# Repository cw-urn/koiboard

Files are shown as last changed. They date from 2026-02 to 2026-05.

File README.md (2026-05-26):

# koiboard
> What is this?
- Koiboard is a 40% ortholinear mechanical low-profile keyboard.
> How do you use it?
- Well you know how to you a keyboard, right? This one just has its keys aligned differently!
> Why did I make this?
- Honestly, I saw the simplicity of the [XYZ Work Board](https://worklouder.cc/xyz-work-board-2), plus other boards, and thought I could make it myself.

<hr>

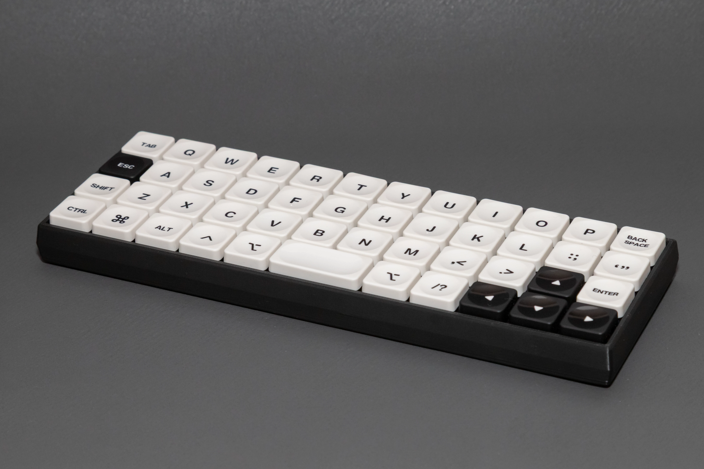
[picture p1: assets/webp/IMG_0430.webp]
Final build


<hr>

## 3D render
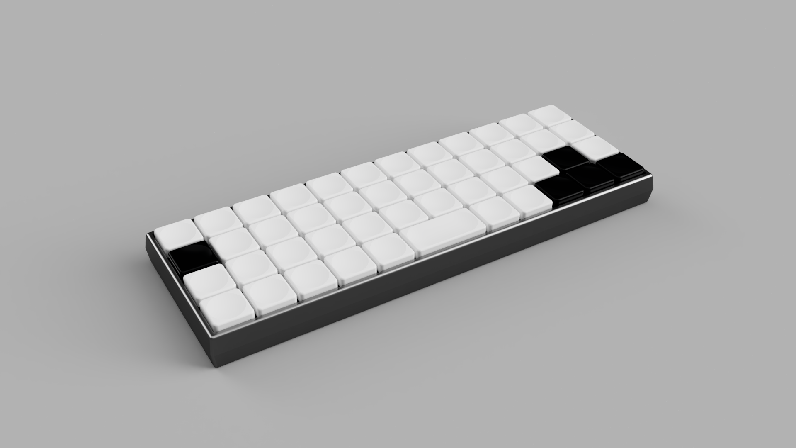
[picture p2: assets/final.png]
3D render


## PCB
[Open online PCB viewer](https://kicanvas.org/?repo=https%3A%2F%2Fgithub.com%2Fcw-urn%2Fkoiboard%2Ftree%2Fmain%2Fpcb)

### Layer 1
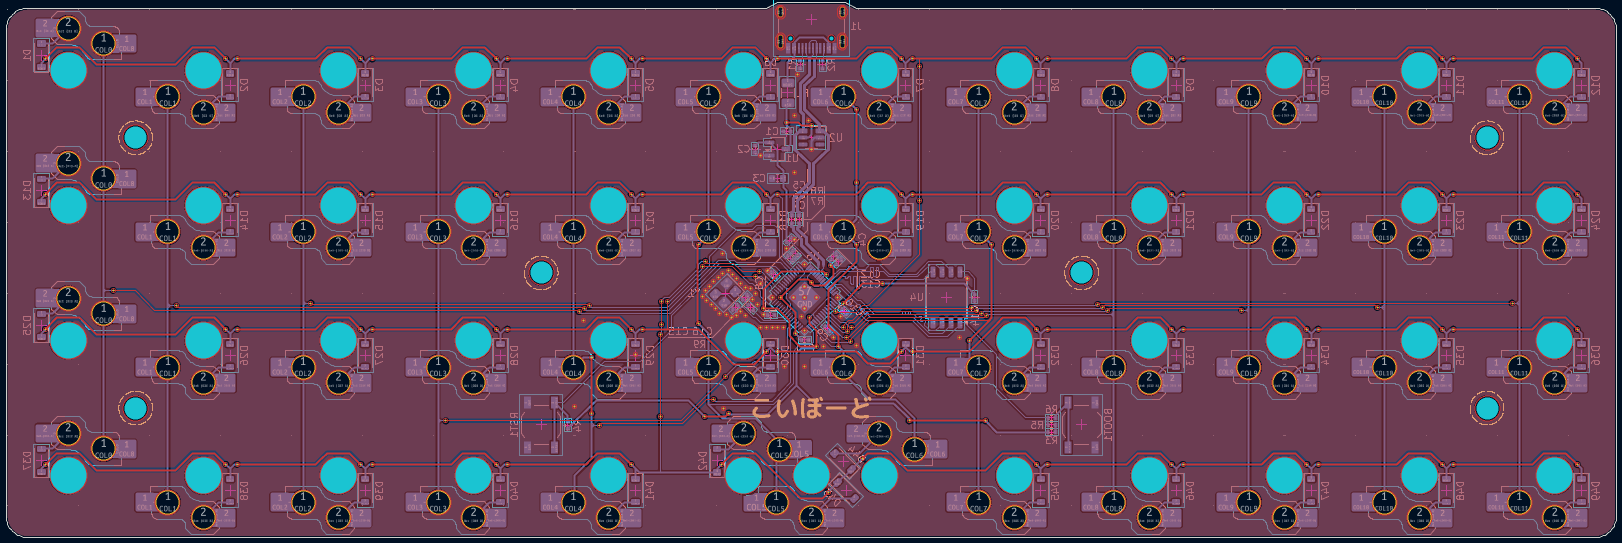
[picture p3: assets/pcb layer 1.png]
Layer 1


### Layer 2
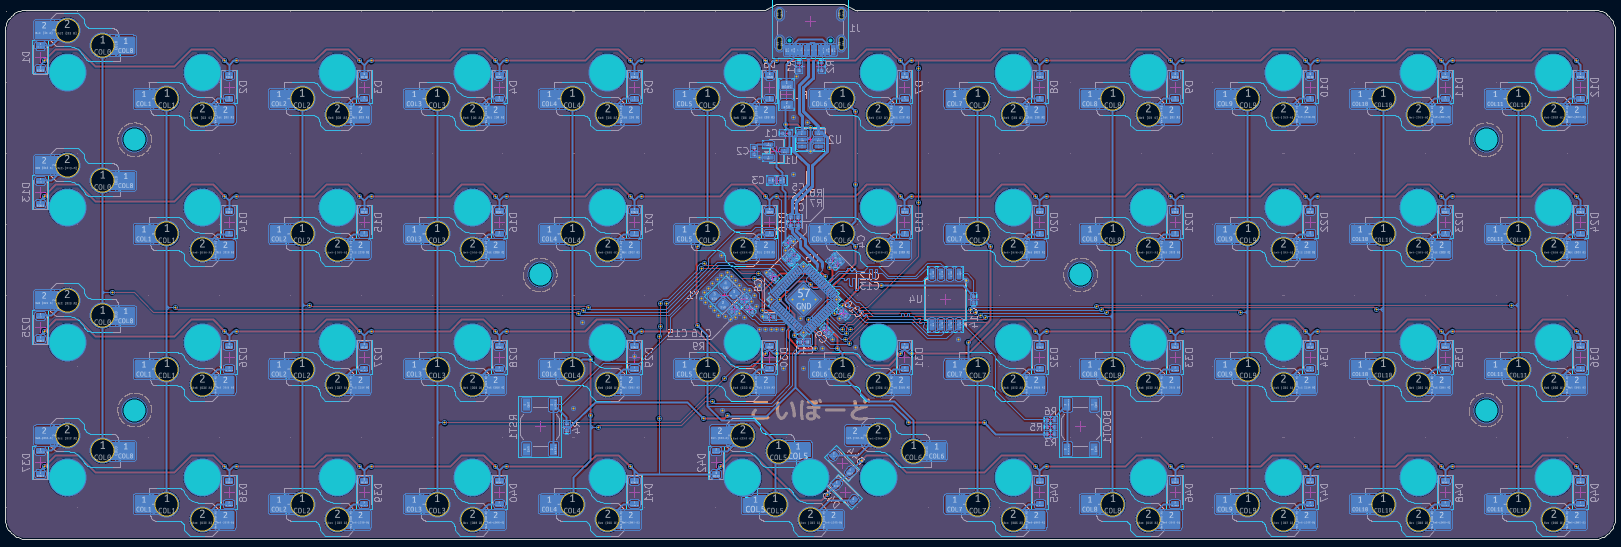
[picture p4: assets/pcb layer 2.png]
Layer 2


### PCB 3D render
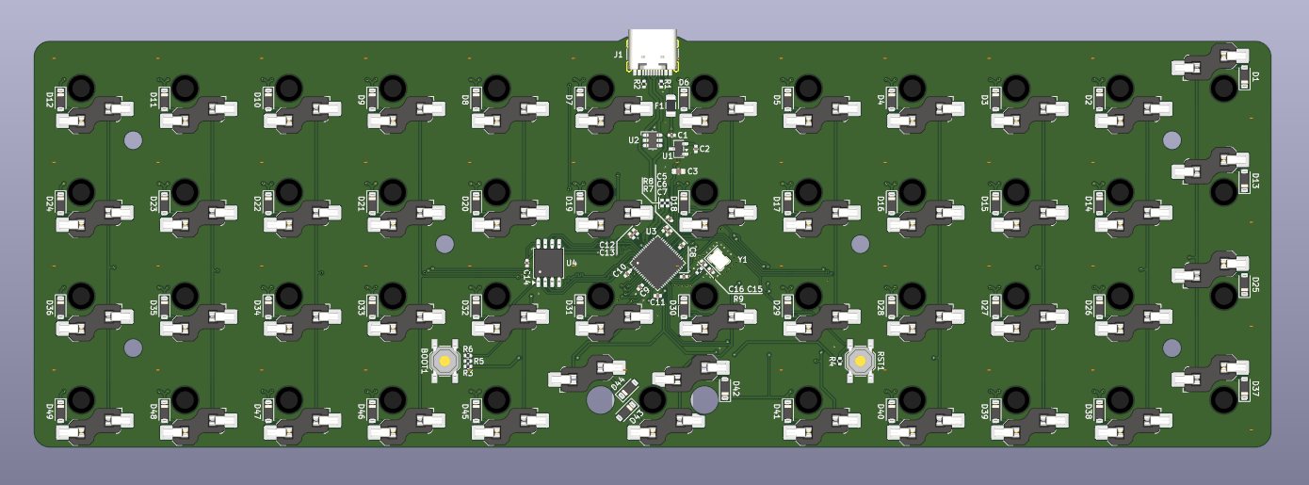
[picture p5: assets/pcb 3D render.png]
3D render of PCB


### Final PCB
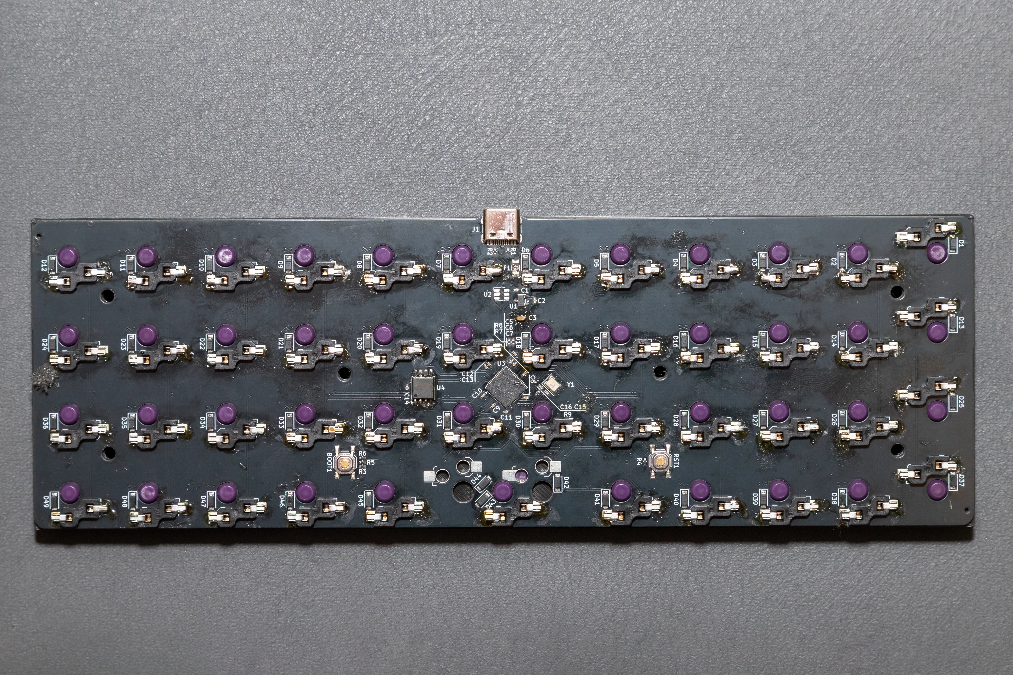
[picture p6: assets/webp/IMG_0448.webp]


### Schematic
This is split up into multiple pages. Check pcb/exports/koiboard.pdf!

## Gallery
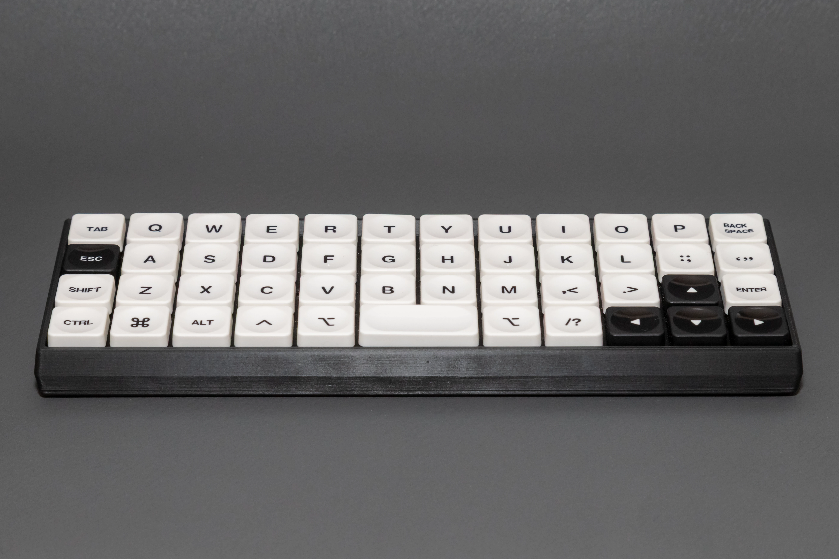
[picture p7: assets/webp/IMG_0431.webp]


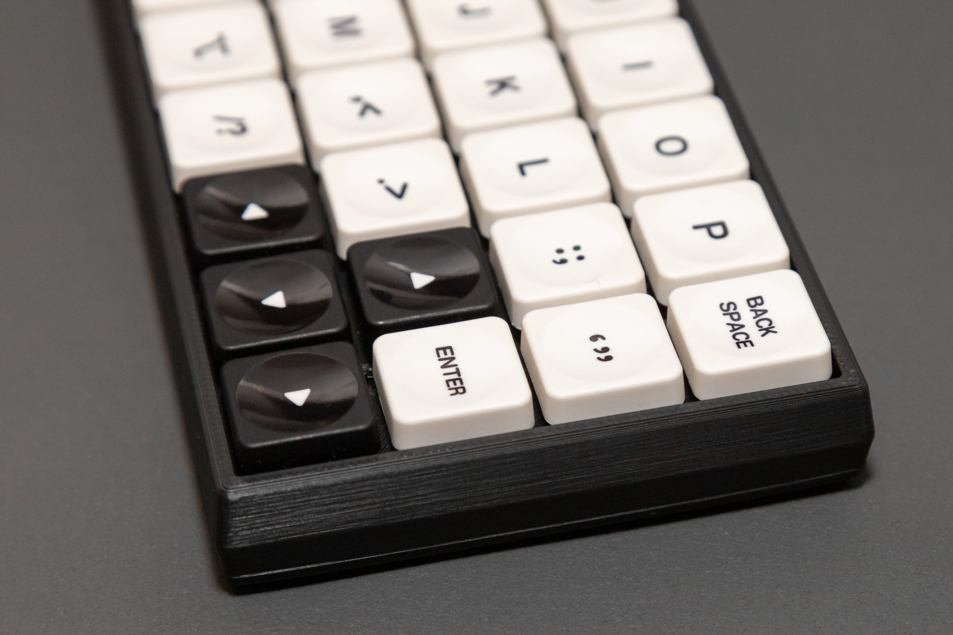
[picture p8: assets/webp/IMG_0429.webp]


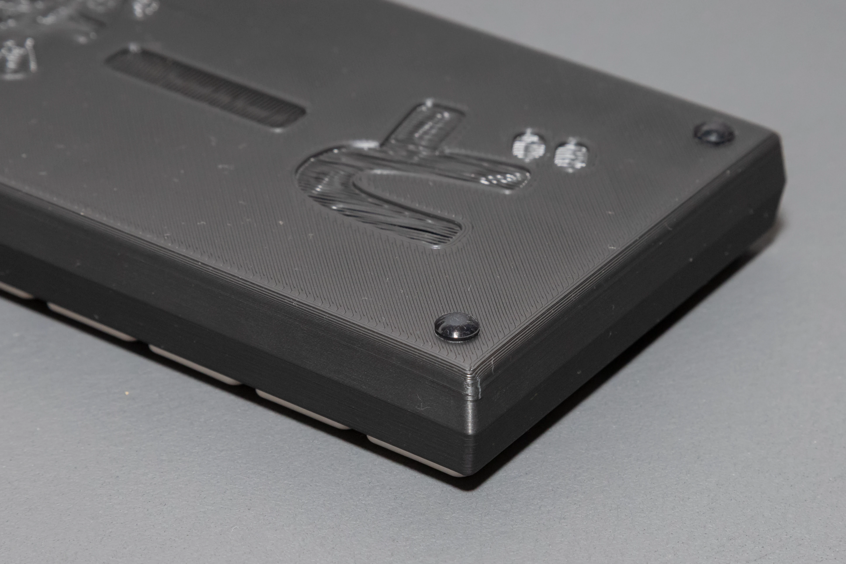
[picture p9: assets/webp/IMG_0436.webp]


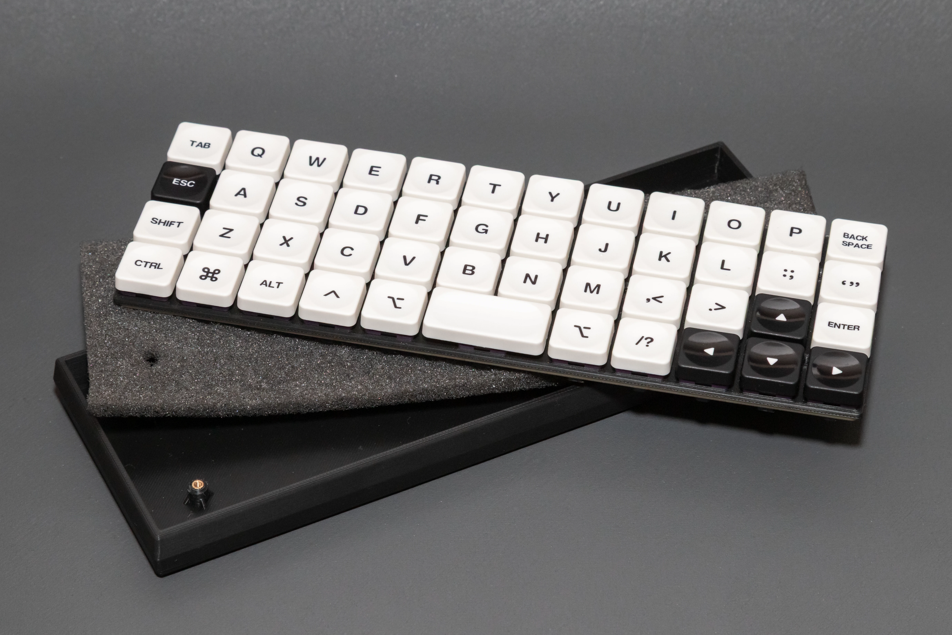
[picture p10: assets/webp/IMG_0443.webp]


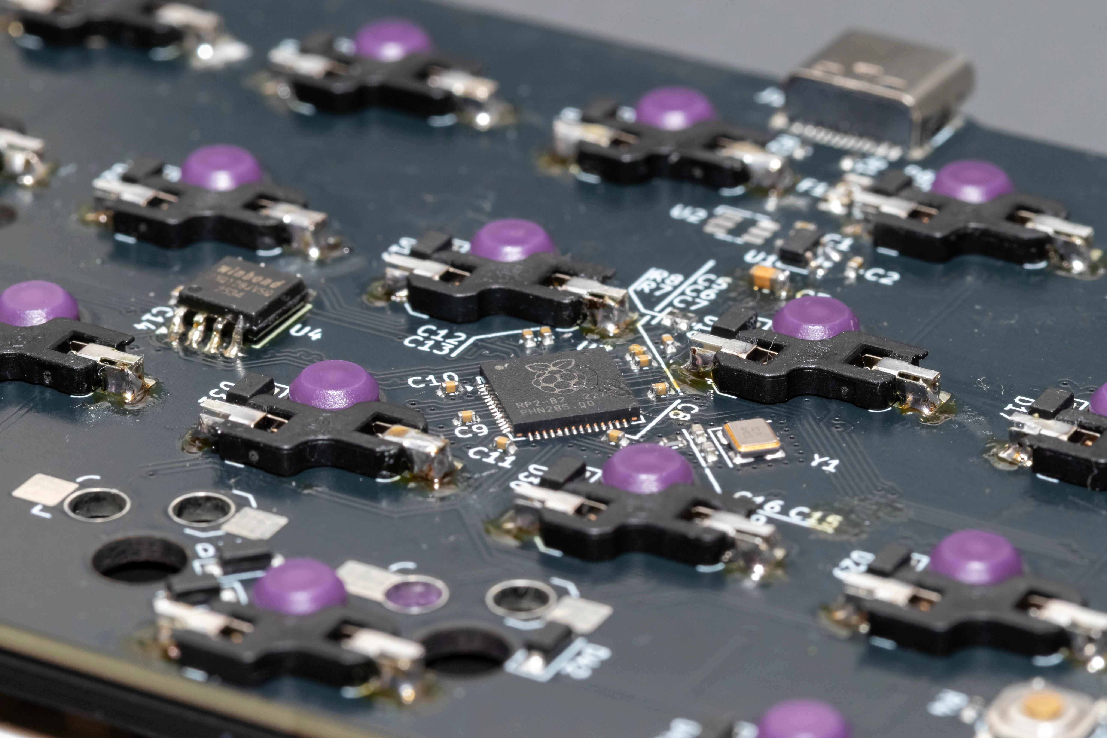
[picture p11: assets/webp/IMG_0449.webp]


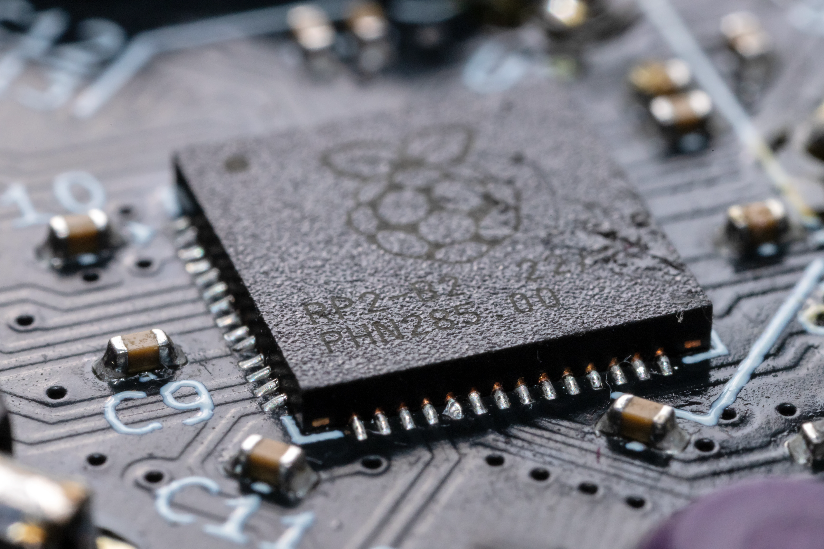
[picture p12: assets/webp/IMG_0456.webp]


More images in assets/webp!!!

## PCB BOM

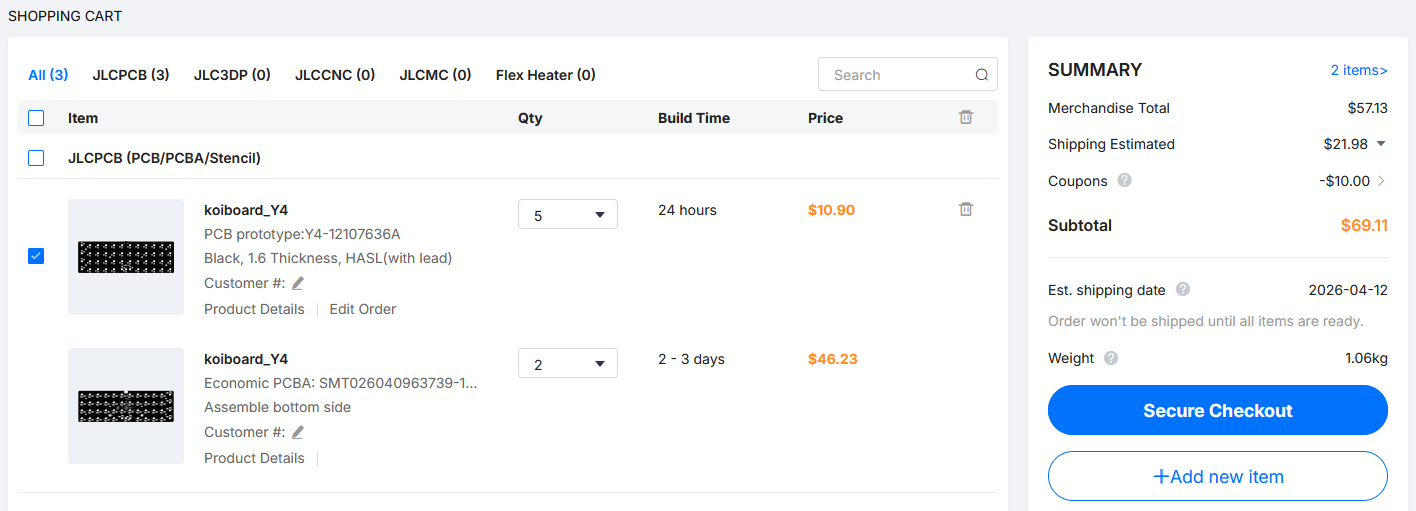
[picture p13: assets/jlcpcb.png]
JLCPCB cart


| Designator | Quantity | Value | LCSC Part # | JLCPCB Link |
| :---: | :---: | :---: | :---: | :---: |
| BOOT1, RST1 | 2 | - | C455262 | [Link](https://jlcpcb.com/partdetail/XUNPU-TS_1087S01526/C455262) |
| C1, C2, C14 | 3 | 1u | C14445 | [Link](https://jlcpcb.com/partdetail/15107-CL05A105KP5NNNC/C14445) |
| C4...13 | 10 | 100n | C1525 | [Link](https://jlcpcb.com/partdetail/1877-CL05B104KO5NNNC/C1525) |
| C15, C16 | 2 | 33p | C1562 | [Link](https://jlcpcb.com/partdetail/1914-0402CG330J500NT/C1562) |
| C3 | 1 | 10u | C1691 | [Link](https://jlcpcb.com/partdetail/2043-CL10A106MQ8NNNC/C1691) |
| **D1...49** | 49 | - | C2099 | [Link](https://jlcpcb.com/partdetail/2456-1N4148W/C2099) |
| F1 | 1 | - | C99563 | [Link](https://jlcpcb.com/partdetail/Littelfuse-1206L075THYR/C99563) |
| J1 | 1 | - | C5370443 | [Link](https://jlcpcb.com/partdetail/Korean_HropartsElec-TYPE_C_31_M40/C5370443) |
| **R1...5** | 5 | 5.1k | C25905 | [Link](https://jlcpcb.com/partdetail/26648-0402WGF5101TCE/C25905) |
| R6, R9 | 2 | 1k | C11702 | [Link](https://jlcpcb.com/partdetail/12256-0402WGF1001TCE/C11702) |
| R7, R8 | 2 | 27 | C25100 | [Link](https://jlcpcb.com/partdetail/25843-0402WGF270JTCE/C25100) |
| U1 | 1 | - | C5446 | [Link](https://jlcpcb.com/partdetail/TorexSemicon-XC6206P332MRG/C5446) |
| U2 | 1 | - | C7519 | [Link](https://jlcpcb.com/partdetail/STMicroelectronics-USBLC62SC6/C7519) |
| U3 | 1 | - | C2040 | [Link](https://jlcpcb.com/partdetail/RaspberryPi-RP2040/C2040) |
| U4 | 1 | - | C97521 | [Link](https://jlcpcb.com/partdetail/WinbondElec-W25Q128JVSIQ/C97521) |
| Y1 | 1 | - | C20625731 | [Link](https://jlcpcb.com/partdetail/AbraconLLC-ABM8_272T3/C20625731) |

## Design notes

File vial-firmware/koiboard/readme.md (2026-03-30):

# koiboard

koiboard

A 40% ortholinear keyboard.

* Keyboard Maintainer: [tomas](https://github.com/cw-urn)
* Hardware Supported: koiboard PCB
* Hardware Availability: *Not for sale*

Make example for this keyboard (after setting up your build environment):

    make koiboard:default

Flashing example for this keyboard:

    make koiboard:default:flash

See the [build environment setup](https://docs.qmk.fm/#/getting_started_build_tools) and the [make instructions](https://docs.qmk.fm/#/getting_started_make_guide) for more information. Brand new to QMK? Start with our [Complete Newbs Guide](https://docs.qmk.fm/#/newbs).

## Bootloader

Enter the bootloader in 3 ways:

* **Bootmagic reset**: Hold down the key at (0,0) in the matrix (usually the top left key or Escape) and plug in the keyboard
* **Physical reset button**: Briefly press the button on the back of the PCB - some may have pads you must short instead
* **Keycode in layout**: Press the key mapped to `QK_BOOT` if it is available

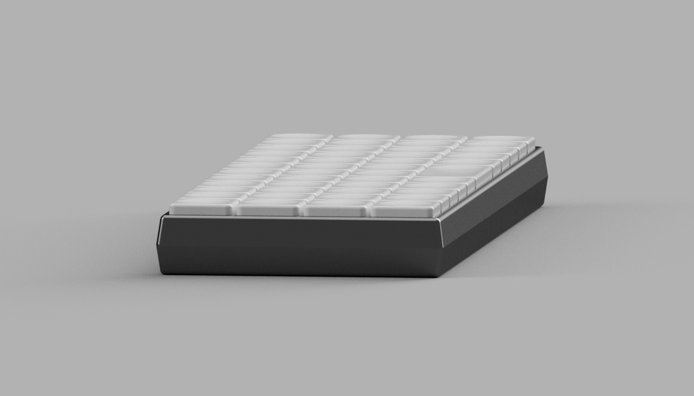
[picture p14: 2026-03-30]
3d design/side.png

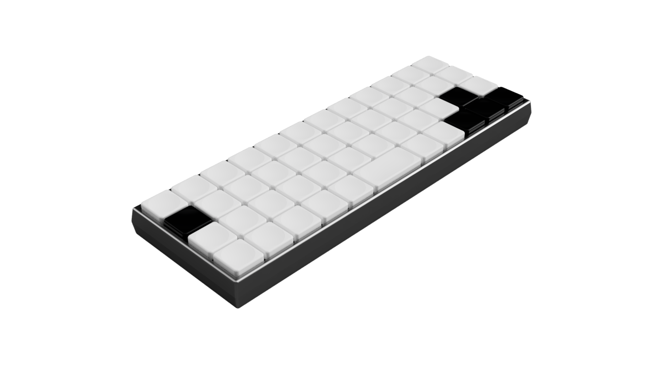
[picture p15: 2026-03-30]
3d design/also not side.PNG

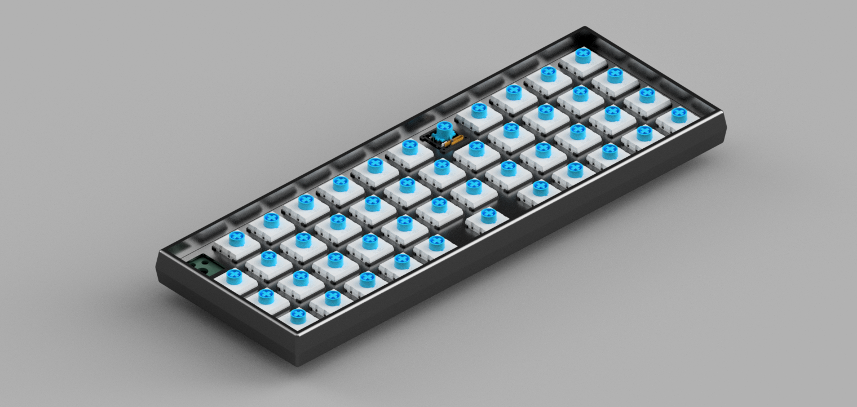
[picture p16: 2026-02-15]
3d design/render.png

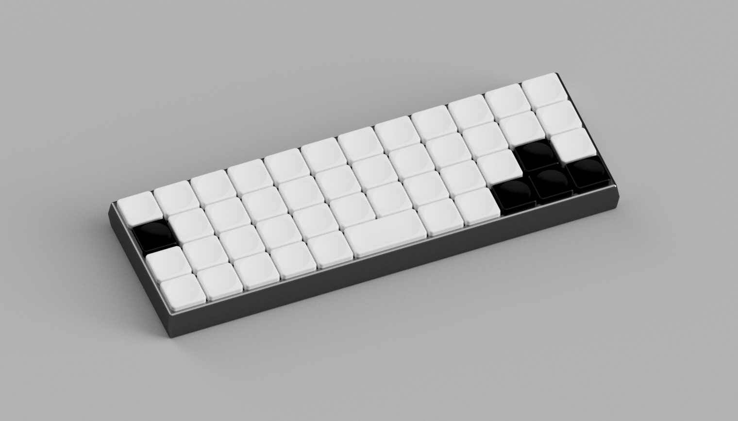
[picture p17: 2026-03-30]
3d design/not side.png

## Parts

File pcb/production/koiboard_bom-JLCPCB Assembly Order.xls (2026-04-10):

JLCPCB BOM Tool - BOM Matching
BOM name：koiboard_bom-JLCPCB Assembly Order.xlsx |  |  | Download Time：2026-04-10 07:47:09 |  |  |  | * Our matching results are updated in real-time, but stock and prices may change. If it's been over 24 hours, please re-match before placing your order.
PCB Assembled Qty：5 |  |  | Est. Total Price：10.4647
Your BOM |  |  |  |  | Matched Parts |  |  |  |  |  |  | Order Information
Top Designator | Bottom Designator | Comment | Footprint | JLCPCB Part # | Matches | Part # | Manufacturer | Footprint | Description | Category | Warning | JLCPCB Part # | Product link | Lib Type | Qty | Source | Total Price ($)
 | BOOT1,RST1 | SW_Push | SW_SPST_TL3342 |  | Unconfirmed | TS-1087S-01526 | XUNPU | SMD,5.2x5.2mm | 1.5mm 100,000 cycles 12V 2.6N 5.2mm 5.2mm 50mA Gull Wing Round Button SPST Surface Mount,Vertical Without Bracket Yellow SMD,5.2x5.2mm Tactile Switches ROHS | Tactile Switches | 1.There may be multiple types of parts, but one type of part has been matched. Please check.; | C455262 | https://jlcpcb.com/partdetail/XUNPU-TS_1087S01526/C455262 | Extended | 5 | 5 JLCPCB | 0.2065
 | C1,C14,C2 | 1u | 0402 |  | Select by Customer | CL05A105KA5NQNC | Samsung Electro-Mechanics | 0402 | 1uF 25V X5R ±10% 0402 Multilayer Ceramic Capacitors MLCC - SMD/SMT ROHS | Multilayer Ceramic Capacitors MLCC - SMD/SMT |  | C52923 | https://jlcpcb.com/partdetail/53938-CL05A105KA5NQNC/C52923 | Basic | 6 | 6 JLCPCB | 0.0246
 | C3 | 10u | 0603 |  | Select by Customer | SDFL1608S100KTF | Sunlord | 0603 | 1.85Ω 10uH 17MHz 30@2MHz 3mA ±10% 0603 Inductors (SMD) ROHS | Inductors (SMD) |  | C1035 | https://jlcpcb.com/partdetail/Sunlord-SDFL1608S100KTF/C1035 | Basic | 2 | 2 JLCPCB | 0.0288
 | C10,C11,C12,C13,C4,C5,C6,C7,C8,C9 | 100n | 0402 |  | Select by System | CL05B104KO5NNNC | Samsung Electro-Mechanics | 0402 | 100nF 16V X7R ±10% 0402 Multilayer Ceramic Capacitors MLCC - SMD/SMT ROHS | Multilayer Ceramic Capacitors MLCC - SMD/SMT |  | C1525 | https://jlcpcb.com/partdetail/1877-CL05B104KO5NNNC/C1525 | Basic | 20 | 20 JLCPCB | 0.026
 | C15,C16 | 33p | 0402 |  | Select by System | 0402CG330J500NT | FH (Guangdong Fenghua Advanced Tech) | 0402 | 33pF 50V C0G ±5% 0402 Multilayer Ceramic Capacitors MLCC - SMD/SMT ROHS | Multilayer Ceramic Capacitors MLCC - SMD/SMT |  | C1562 | https://jlcpcb.com/partdetail/1914-0402CG330J500NT/C1562 | Basic | 4 | 4 JLCPCB | 0.0048
 | D1,D10,D11,D12,D13,D14,D15,D16,D17,D18,D19,D2,D20,D21,D22,D23,D24,D25,D26,D27,D28,D29,D3,D30,D31,D32,D33,D34,D35,D36,D37,D38,D39,D4,D40,D41,D42,D43,D44,D45,D46,D47,D48,D49,D5,D6,D7,D8,D9 | D_Small | D_SOD-123 |  | Select by System | 1N4148W | Jiangsu Changjing Electronics Technology Co., Ltd. | SOD-123 | 1.25V@150mA 100V 150mA 1uA@75V 2A 4ns 500mW Independent SOD-123 Switching Diodes ROHS | Switching Diodes |  | C2099 | https://jlcpcb.com/partdetail/2456-1N4148W/C2099 | Extended | 110 | 110 JLCPCB | 1.034
 | F1 | Fuse_Small | 1206 |  | Select by System | 1206L075THYR | Littelfuse | 1206 | -40℃~+85℃ 1.5A 100A 16V 200ms 290mΩ 600mW 750mA 90mΩ 1206 Resettable Fuses ROHS | Resettable Fuses |  | C99563 | https://jlcpcb.com/partdetail/Littelfuse-1206L075THYR/C99563 | Extended | 6 | 6 JLCPCB | 0.288
 | J1 | USB_C_Receptacle_USB2.0_16P | USB_C_Receptacle_HRO_TYPE-C-31-M-12 |  | Select by Customer | TYPE-C-31-M-12 | Korean Hroparts Elec | SMD | -30℃~+80℃ 1 10,000 cycles 16P 20V 5A 7.35mm Female Surface Mount, Right Angle Type-C SMD USB Connectors ROHS | USB Connectors |  | C165948 | https://jlcpcb.com/partdetail/Korean_HropartsElec-TYPE_C_31_M12/C165948 | Extended | 2 | 2 JLCPCB | 0.3662
 | R1,R2,R3,R4,R5 | 5.1k | 0402 |  | Select by System | 0402WGF5101TCE | UNI-ROYAL(Uniroyal Elec) | 0402 | -55℃~+155℃ 5.1kΩ 50V 62.5mW Thick Film Resistor ±1% ±100ppm/℃ 0402 Chip Resistor - Surface Mount ROHS | Chip Resistor - Surface Mount |  | C25905 | https://jlcpcb.com/partdetail/26648-0402WGF5101TCE/C25905 | Basic | 10 | 10 JLCPCB | 0.008
 | R6,R9 | 1k | 0402 |  | Select by System | 0402WGF1001TCE | UNI-ROYAL(Uniroyal Elec) | 0402 | -55℃~+155℃ 1kΩ 50V 62.5mW Thick Film Resistor ±1% ±100ppm/℃ 0402 Chip Resistor - Surface Mount ROHS | Chip Resistor - Surface Mount |  | C11702 | https://jlcpcb.com/partdetail/12256-0402WGF1001TCE/C11702 | Basic | 4 | 4 JLCPCB | 0.0028
 | R7,R8 | 27 | 0402 |  | Select by System | 0402WGF270JTCE | UNI-ROYAL(Uniroyal Elec) | 0402 | -55℃~+155℃ 27Ω 50V 62.5mW Thick Film Resistor ±1% ±100ppm/℃ 0402 Chip Resistor - Surface Mount ROHS | Chip Resistor - Surface Mount |  | C25100 | https://jlcpcb.com/partdetail/25843-0402WGF270JTCE/C25100 | Extended | 20 | 20 JLCPCB | 0.016
 | U1 | XC6206PxxxMR | SOT-23-3 |  | Select by System | XC6206P332MR-G | Torex Semicon | SOT-23-3L | -40℃~+85℃@(Ta) 1 1uA 200mA 3.3V 6V Fixed Over Current Protection Positive SOT-23-3L Voltage Regulators - Linear, Low Drop Out (LDO) Regulators ROHS | Voltage Regulators - Linear, Low Drop Out (LDO) Regulators |  | C5446 | https://jlcpcb.com/partdetail/TorexSemicon-XC6206P332MRG/C5446 | Basic | 2 | 2 JLCPCB | 0.2118
 | U2 | SRV05-4 | SOT-23-6-routable |  | Select by System | USBLC6-2SC6 | STMicroelectronics | SOT-23-6L | -40℃~+125℃ 150nA 17V 2 3.5pF 5.25V 5A 6V ESD IEC 61000-4-2 Unidirectional SOT-23-6L ESD and Surge Protection (TVS/ESD) ROHS | ESD And Surge Protection (TVS/ESD) |  | C7519 | https://jlcpcb.com/partdetail/STMicroelectronics-USBLC62SC6/C7519 | Extended | 5 | 5 JLCPCB | 0.773
 | U3 | RP2040 | QFN-56-1EP_7x7mm_P0.4mm_EP3.2x3.2mm |  | Select by System | RP2040 | Raspberry Pi | LQFN-56(7x7) | 12bit 133MHz 30 LQFN-56(7x7) Microcontrollers (MCU/MPU/SOC) ROHS | Microcontrollers (MCU/MPU/SOC) |  | C2040 | https://jlcpcb.com/partdetail/RaspberryPi-RP2040/C2040 | Extended | 2 | 2 JLCPCB | 1.9518
 | U4 | W25Q128JVS | SOIC-8_5.3x5.3mm_P1.27mm |  | Select by System | W25Q128JVSIQ | Winbond Elec | SOIC-8-208mil | -40℃~+85℃ 100,000 cycles 120ms@(32KB) 128Mbit 133MHz 1uA 2.7V~3.6V 20 Years 3ms SPI SOIC-8-208mil NOR FLASH ROHS | NOR FLASH |  | C97521 | https://jlcpcb.com/partdetail/WinbondElec-W25Q128JVSIQ/C97521 | Basic | 2 | 2 JLCPCB | 4.0694
 | Y1 | Crystal_GND24 | Crystal_SMD_3225-4Pin_3.2x2.5mm |  | Select by System | ABM8-272-T3 | Abracon LLC | SMD3225-4P | -40℃~+85℃ 10pF 12MHz 50Ω Crystal Oscillator ±30ppm ±30ppm SMD3225-4P Crystals ROHS | Crystals |  | C20625731 | https://jlcpcb.com/partdetail/AbraconLLC-ABM8_272T3/C20625731 | Extended | 5 | 5 JLCPCB | 1.453

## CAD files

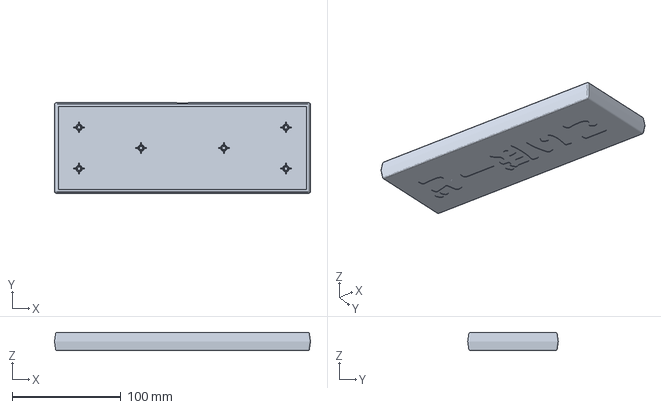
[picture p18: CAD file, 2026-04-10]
3d design/case.3mf
235.9 x 83.5 x 17.0 mm

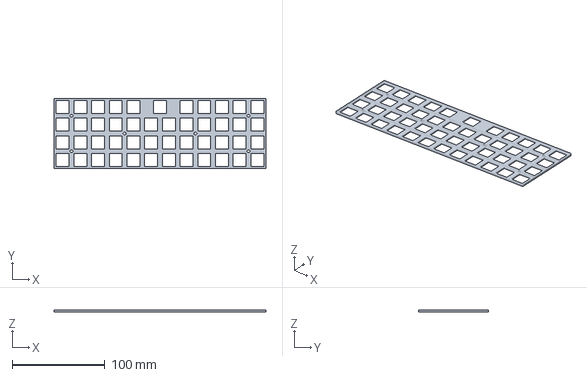
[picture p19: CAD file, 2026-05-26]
3d design/plate design/plate.3mf
228.2 x 75.8 x 2.10 mm

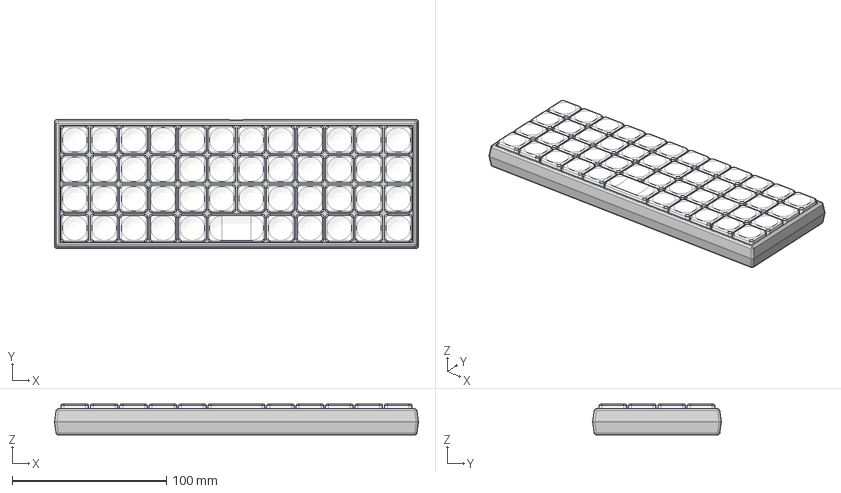
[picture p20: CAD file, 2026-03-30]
koiboard.step
235.9 x 83.5 x 20.0 mm

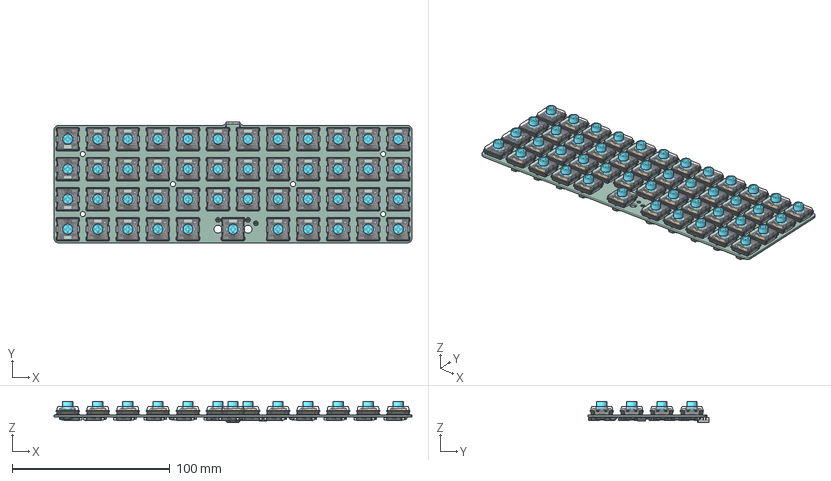
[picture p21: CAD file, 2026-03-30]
pcb/exports/final_pcb.step
227.0 x 76.7 x 13.4 mm
D_SOD-123 x 49
C_0402_1005Metric x 15
pin x 98
socket x 49
bottom x 47
contact x 47
pin1 x 47
stem x 47
top x 47
pin2 x 47
pin3 x 47
click_bar x 47
shrunken_spring x 47
R_0402_1005Metric x 9
SOT-23-3
SW_SPST_TL3342 x 2
Fuse_1206_3216Metric
SOT-23-6
SOIC-8_5.3x5.3mm_P1.27mm
QFN-56-1EP_7x7mm_P0.4mm_EP3.2x3.2mm
Crystal_SMD_3225-4Pin_3.2x2.5mm
C_0603_1608Metric
USB_C_Receptacle_GCT_USB4105-xx-A_16P_TopMnt_Horizontal
koiboard2_PCB

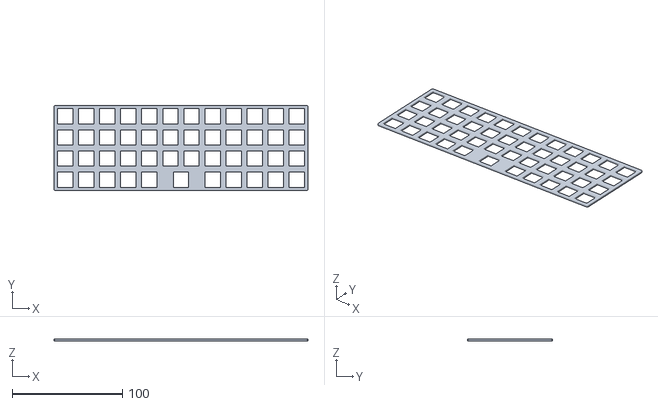
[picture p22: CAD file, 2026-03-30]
3d design/plate design/Body1.stl
230.0 x 77.0 x 1.60

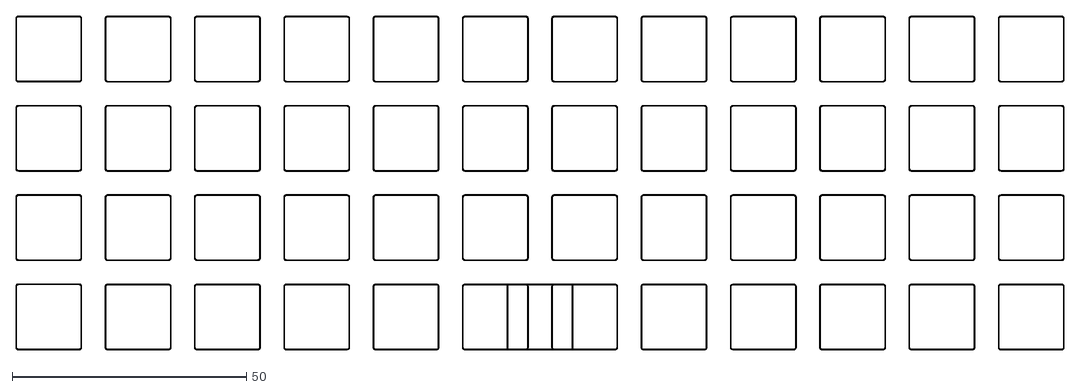
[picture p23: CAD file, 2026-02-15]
3d design/plate design/koiboard2-User_Eco2.dxf
223.5 x 71.1

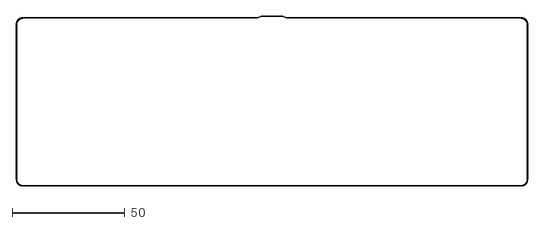
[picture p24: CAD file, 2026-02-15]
3d design/plate design/koiboard2-Edge_Cuts.dxf
227.0 x 75.5

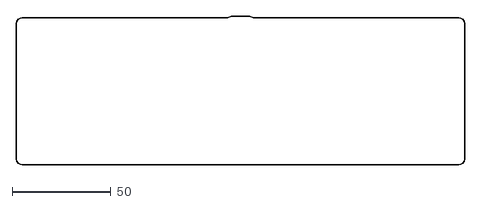
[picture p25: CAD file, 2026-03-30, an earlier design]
pcb/production/_old3/koiboard2-Edge_Cuts.dxf
227.0 x 75.4

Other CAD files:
3d design/case.stl
3d design/koiboard.f3z
3d design/plate design/plate.stl

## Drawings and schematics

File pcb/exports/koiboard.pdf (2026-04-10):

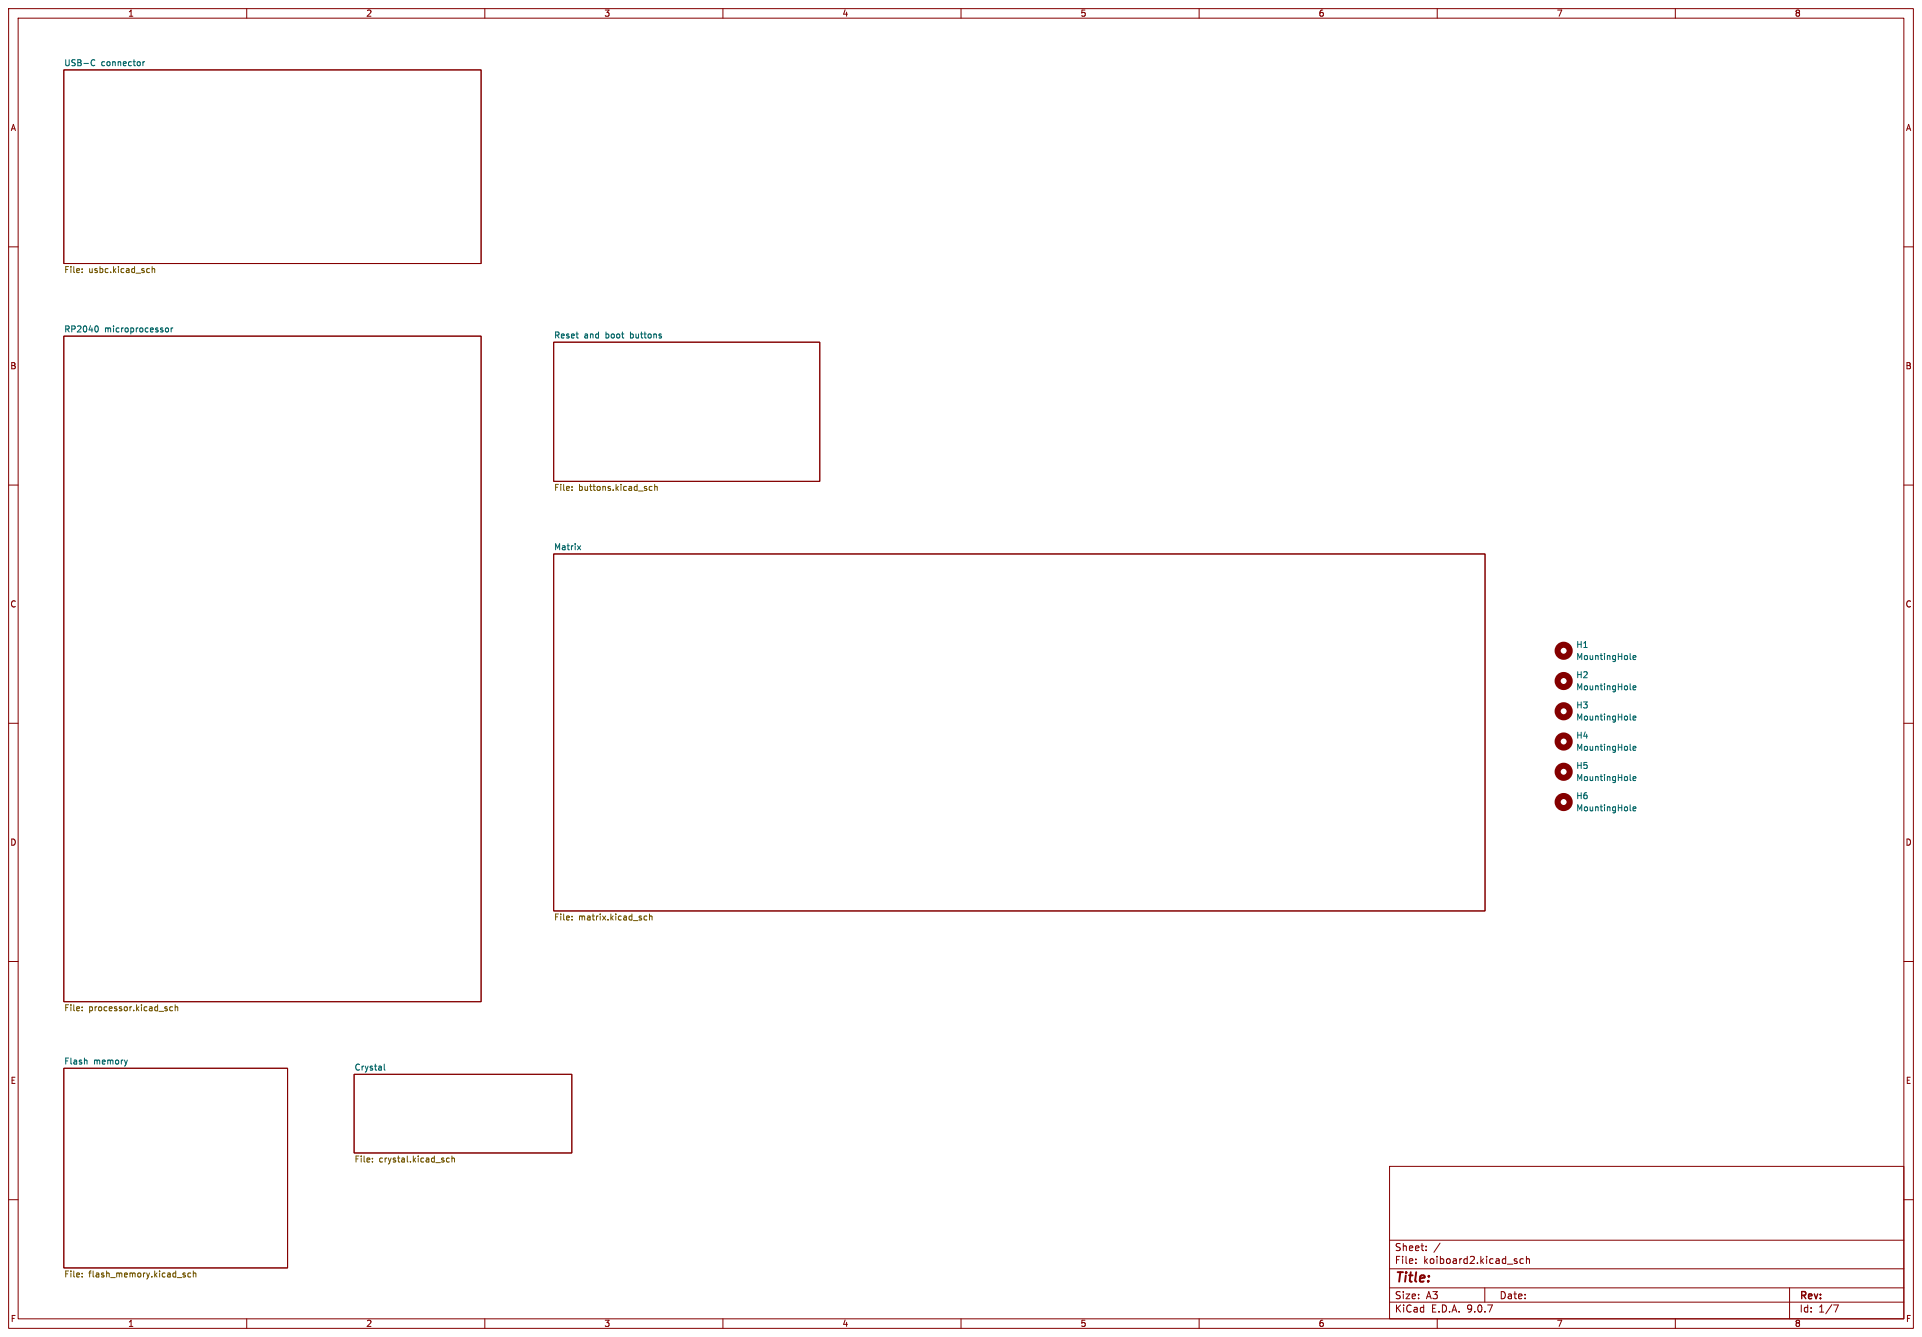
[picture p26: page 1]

USB-C connector File: usbc.kicad_sch RP2040 microprocessor

Crystal File: crystal.kicad_sch Flash memory File: flash_memory.kicad_sch

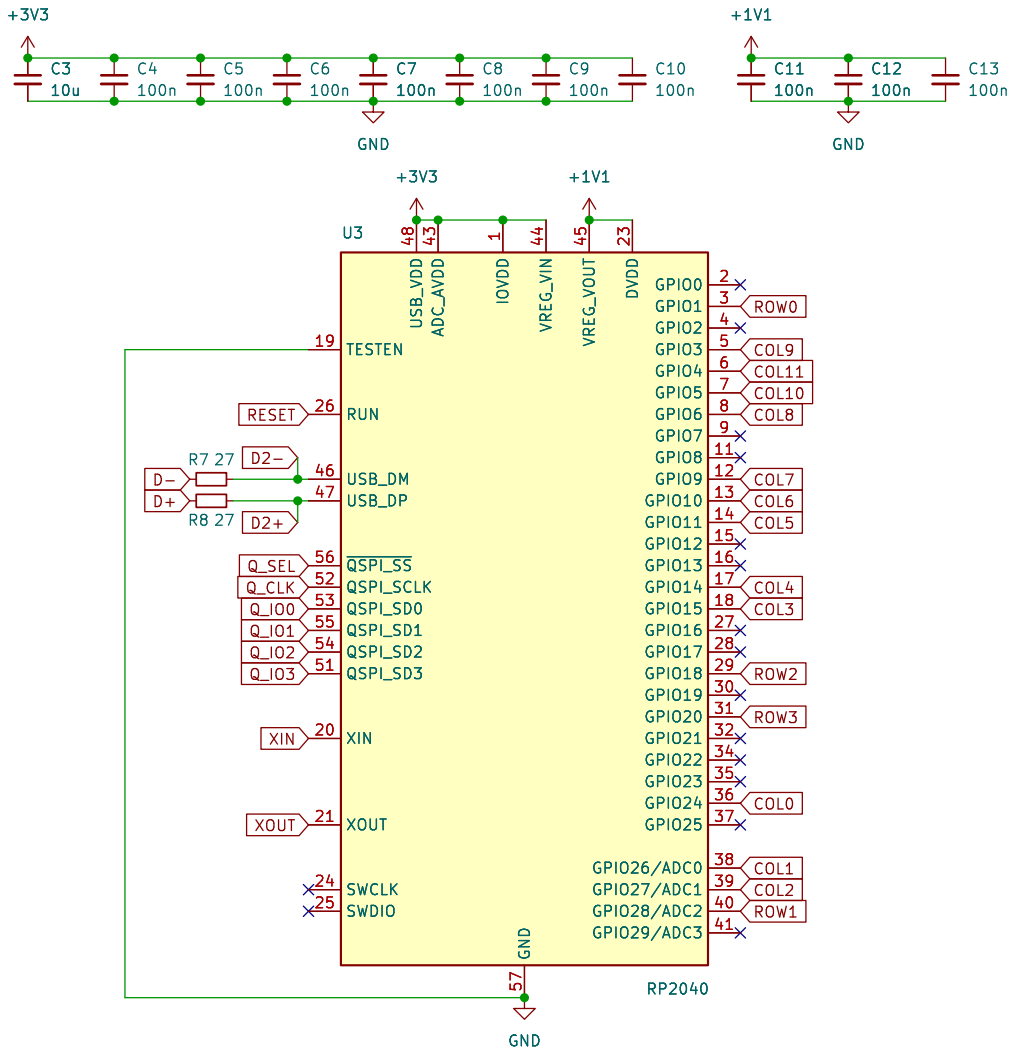
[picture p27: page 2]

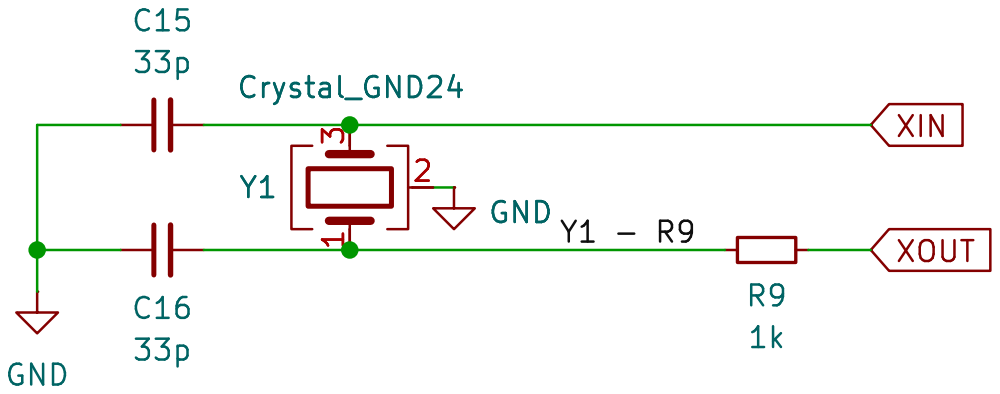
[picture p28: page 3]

Id: 3/7 Title: File: crystal.kicad_sch Sheet: /Crystal/ C16

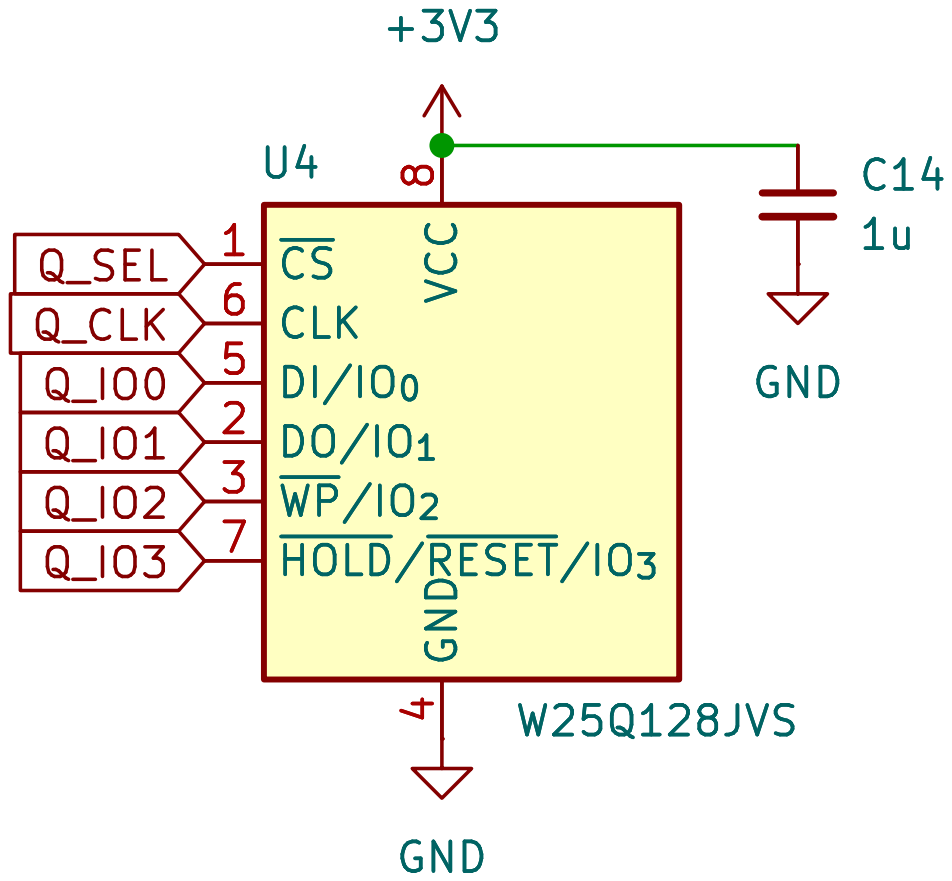
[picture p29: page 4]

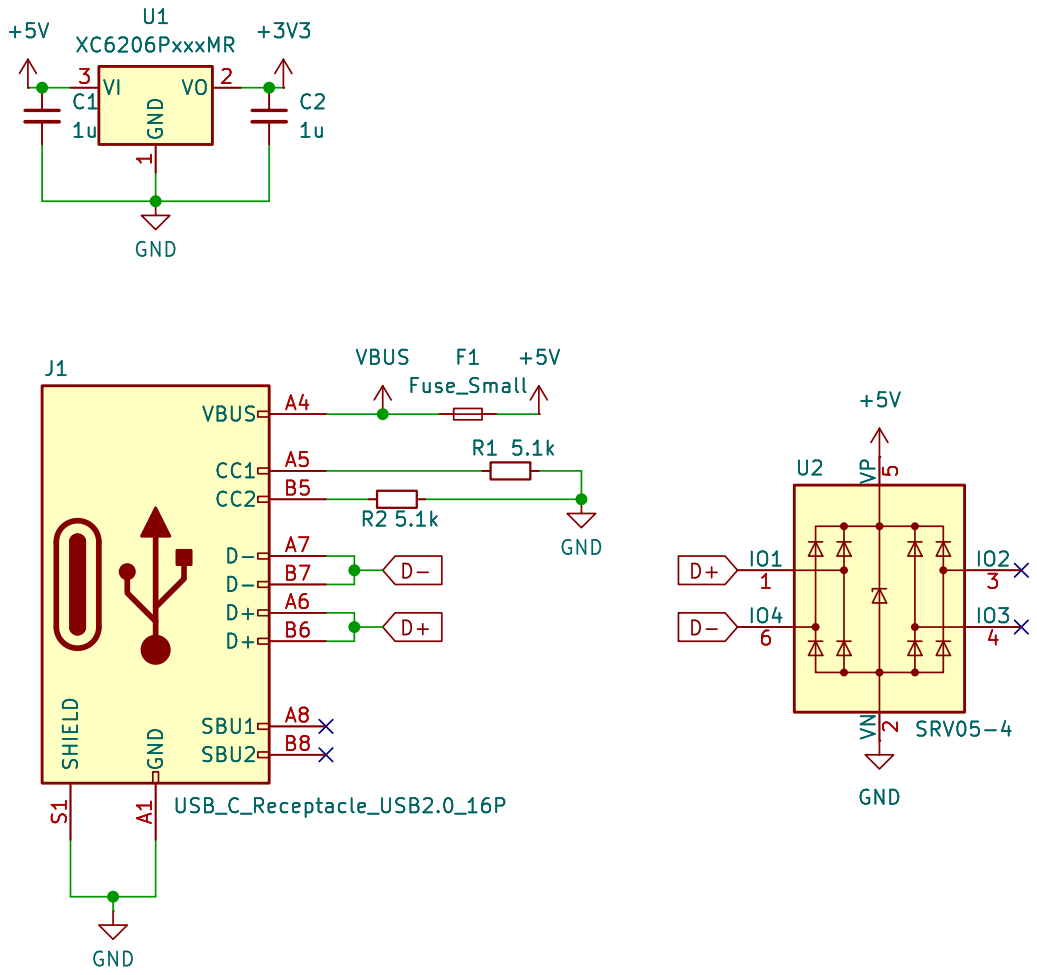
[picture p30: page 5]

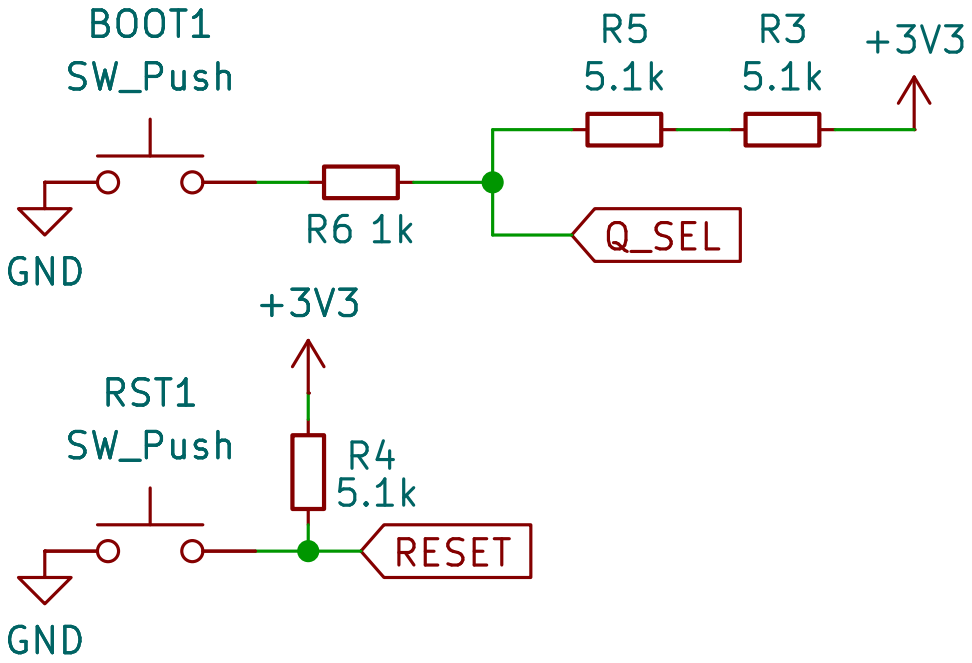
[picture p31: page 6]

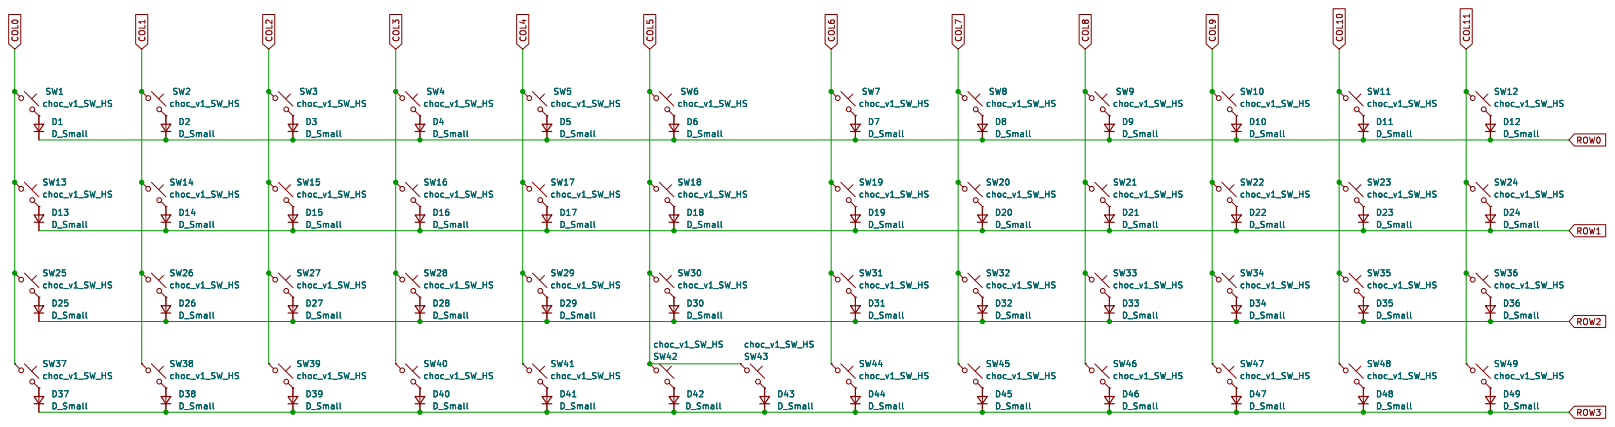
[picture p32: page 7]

Id: 7/7 Title: File: matrix.kicad_sch Sheet: /Matrix/

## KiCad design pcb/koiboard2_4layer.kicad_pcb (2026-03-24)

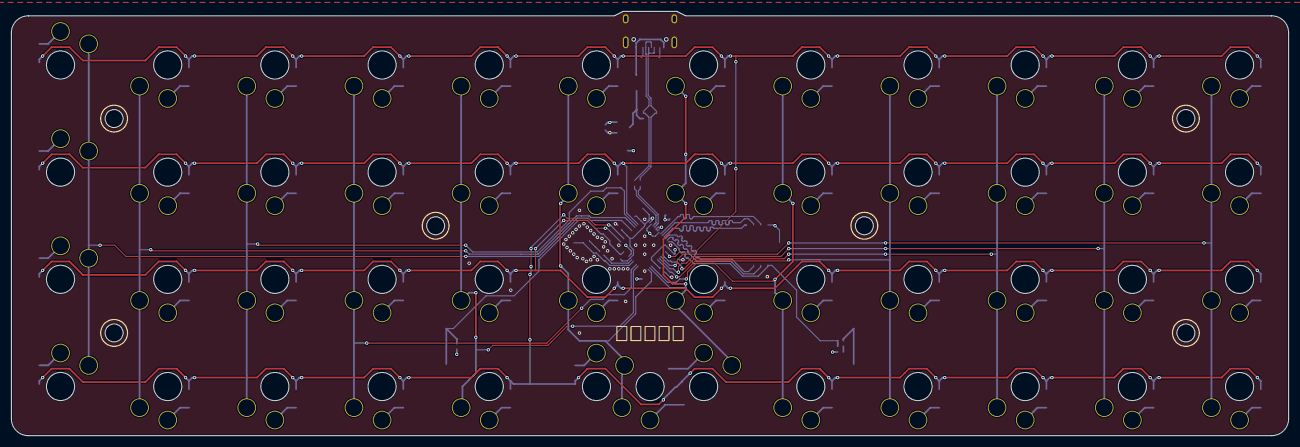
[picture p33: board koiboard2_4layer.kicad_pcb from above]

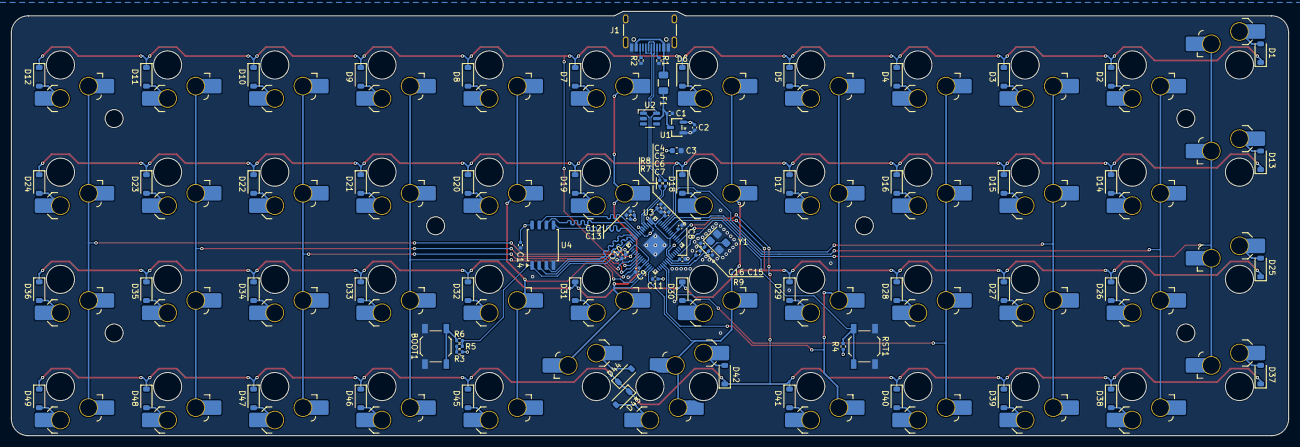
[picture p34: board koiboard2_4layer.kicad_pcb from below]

Board: 4 copper layers, 227.0 x 75.4 mm, 138 parts (132 on the bottom side), 88 nets.

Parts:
BOOT1: SW_Push; SW_SPST_TL3342
C1, C2, C14: 1u; C_0402_1005Metric
C3: 10u; C_0603_1608Metric
C4, C5, C6, C7, C8, C9, C10, C11, C12, C13: 100n; C_0402_1005Metric
C15, C16: 33p; C_0402_1005Metric
D1, D2, D3, D4, D5, D6, D7, D8, D9, D10, D11, D12, D13, D14, D15, D16, D17, D18, D19, D20, D21, D22, D23, D24, D25, D26, D27, D28, D29, D30, D31, D32, D33, D34, D35, D36, D37, D38, D39, D40, D41, D42, D43, D44, D45, D46, D47, D48, D49: D_Small; D_SOD-123
F1: Fuse_Small; Fuse_1206_3216Metric
H1, H2, H3, H4, H5, H6: MountingHole; MountingHole_3.2mm_M3_ISO14580
J1: USB_C_Receptacle_USB2.0_16P; USB_C_Receptacle_HRO_TYPE-C-31-M-12
R1, R2, R3, R4, R5: 5.1k; R_0402_1005Metric
R6, R9: 1k; R_0402_1005Metric
R7, R8: 27; R_0402_1005Metric
RST1: SW_Push; SW_SPST_TL3342
SW1, SW2, SW3, SW4, SW5, SW6, SW7, SW8, SW9, SW10, SW11, SW12, SW13, SW14, SW15, SW16, SW17, SW18, SW19, SW20, SW21, SW22, SW23, SW24, SW25, SW26, SW27, SW28, SW29, SW30, SW31, SW32, SW33, SW34, SW35, SW36, SW37, SW38, SW39, SW40, SW41, SW45, SW46, SW47, SW48, SW49: choc_v1_SW_HS; SW_choc_v2_HS_CPG135001S30_1u
SW42: choc_v1_SW_HS; SW_choc_v2_HS_CPG135001S30_1u_SW42
SW43: choc_v1_SW_HS; SW_choc_v2_HS_CPG135001S30_1u_SW42_switch_show
SW44: choc_v1_SW_HS; SW_choc_v2_HS_CPG135001S30_1u_switch_hide
U1: XC6206PxxxMR; SOT-23-3
U2: SRV05-4; SOT-23-6-routable
U3: RP2040; QFN-56-1EP_7x7mm_P0.4mm_EP3.2x3.2mm
U4: W25Q128JVS; SOIC-8_5.3x5.3mm_P1.27mm
Y1: Crystal_GND24; Crystal_SMD_3225-4Pin_3.2x2.5mm

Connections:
+1V1: C11.1, C12.1, C13.1, U3.23 (DVDD), U3.45 (VREG_VOUT), U3.50 (DVDD)
+3V3: C2.1, C3.1, C4.1, C5.1, C6.1, C7.1, C8.1, C9.1, C10.1, C14.1, R3.1, R4.2, U1.2 (VO), U3.1 (IOVDD), U3.10 (IOVDD), U3.22 (IOVDD), U3.33 (IOVDD), U3.42 (IOVDD), U3.43 (ADC_AVDD), U3.44 (VREG_VIN), U3.48 (USB_VDD), U3.49 (IOVDD), U4.8 (VCC)
+5V: C1.1, F1.2, U1.3 (VI), U2.5 (VP)
/Crystal/Y1 - R9: C16.2, R9.1, Y1.1
COL0: SW1.1, SW13.1, SW25.1, SW37.1, U3.36 (GPIO24)
COL1: SW2.1, SW14.1, SW26.1, SW38.1, U3.38 (GPIO26/ADC0)
COL2: SW3.1, SW15.1, SW27.1, SW39.1, U3.39 (GPIO27/ADC1)
COL3: SW4.1, SW16.1, SW28.1, SW40.1, U3.18 (GPIO15)
COL4: SW5.1, SW17.1, SW29.1, SW41.1, U3.17 (GPIO14)
COL5: SW6.1, SW18.1, SW30.1, SW42.1, SW43.1, U3.14 (GPIO11)
COL6: SW7.1, SW19.1, SW31.1, SW44.1, U3.13 (GPIO10)
COL7: SW8.1, SW20.1, SW32.1, SW45.1, U3.12 (GPIO9)
COL8: SW9.1, SW21.1, SW33.1, SW46.1, U3.8 (GPIO6)
COL9: SW10.1, SW22.1, SW34.1, SW47.1, U3.5 (GPIO3)
COL10: SW11.1, SW23.1, SW35.1, SW48.1, U3.7 (GPIO5)
COL11: SW12.1, SW24.1, SW36.1, SW49.1, U3.6 (GPIO4)
D+: J1.A6 (D+), J1.B6 (D+), R8.1, U2.1 (IO1)
D-: J1.A7 (D-), J1.B7 (D-), R7.1, U2.6 (IO4)
GND: BOOT1.1, C1.2, C2.2, C3.2, C4.2, C5.2, C6.2, C7.2, C8.2, C9.2, C10.2, C11.2, C12.2, C13.2, C14.2, C15.1, C16.1, J1.A1 (GND), J1.A12 (GND), J1.B1 (GND), J1.B12 (GND), J1.S1 (SHIELD), R1.2, R2.2, RST1.1, U1.1 (GND), U2.2 (VN), U3.19 (TESTEN), U3.57 (GND), U4.4 (GND), Y1.2 (G), Y1.4 (G)
unnamed: BOOT1.2, R6.1
unnamed: D1.2 (A), SW1.2
unnamed: D2.2 (A), SW2.2
unnamed: D3.2 (A), SW3.2
unnamed: D4.2 (A), SW4.2
unnamed: D5.2 (A), SW5.2
unnamed: D6.2 (A), SW6.2
unnamed: D7.2 (A), SW7.2
unnamed: D8.2 (A), SW8.2
unnamed: D9.2 (A), SW9.2
unnamed: D10.2 (A), SW10.2
unnamed: D11.2 (A), SW11.2
unnamed: D12.2 (A), SW12.2
unnamed: D13.2 (A), SW13.2
unnamed: D14.2 (A), SW14.2
unnamed: D15.2 (A), SW15.2
unnamed: D16.2 (A), SW16.2
unnamed: D17.2 (A), SW17.2
unnamed: D18.2 (A), SW18.2
unnamed: D19.2 (A), SW19.2
unnamed: D20.2 (A), SW20.2
unnamed: D21.2 (A), SW21.2
unnamed: D22.2 (A), SW22.2
unnamed: D23.2 (A), SW23.2
unnamed: D24.2 (A), SW24.2
unnamed: D25.2 (A), SW25.2
unnamed: D26.2 (A), SW26.2
unnamed: D27.2 (A), SW27.2
unnamed: D28.2 (A), SW28.2
unnamed: D29.2 (A), SW29.2
unnamed: D30.2 (A), SW30.2
unnamed: D31.2 (A), SW31.2
unnamed: D32.2 (A), SW32.2
unnamed: D33.2 (A), SW33.2
unnamed: D34.2 (A), SW34.2
unnamed: D35.2 (A), SW35.2
unnamed: D36.2 (A), SW36.2
unnamed: D37.2 (A), SW37.2
unnamed: D38.2 (A), SW38.2
unnamed: D39.2 (A), SW39.2
unnamed: D40.2 (A), SW40.2
unnamed: D41.2 (A), SW41.2
unnamed: D42.2 (A), SW42.2
unnamed: D43.2 (A), SW43.2
unnamed: D44.2 (A), SW44.2
unnamed: D45.2 (A), SW45.2
unnamed: D46.2 (A), SW46.2
unnamed: D47.2 (A), SW47.2
unnamed: D48.2 (A), SW48.2
unnamed: D49.2 (A), SW49.2
unnamed: J1.A5 (CC1), R1.1
unnamed: J1.B5 (CC2), R2.1
unnamed: R3.2, R5.2
unnamed: R7.2, U3.46 (USB_DM)
unnamed: R8.2, U3.47 (USB_DP)
Q_CLK: U3.52 (QSPI_SCLK), U4.6 (CLK)
Q_IO0: U3.53 (QSPI_SD0), U4.5 (DI/IO_{0})
Q_IO1: U3.55 (QSPI_SD1), U4.2 (DO/IO_{1})
Q_IO2: U3.54 (QSPI_SD2), U4.3 (~WP/IO_{2})
Q_IO3: U3.51 (QSPI_SD3), U4.7 (~HOLD/~RESET/IO_{3})
Q_SEL: R5.1, R6.2, U3.56 (~QSPI_SS), U4.1 (~CS)
RESET: R4.1, RST1.2, U3.26 (RUN)
ROW0: D1.1 (K), D2.1 (K), D3.1 (K), D4.1 (K), D5.1 (K), D6.1 (K), D7.1 (K), D8.1 (K), D9.1 (K), D10.1 (K), D11.1 (K), D12.1 (K), U3.3 (GPIO1)
ROW1: D13.1 (K), D14.1 (K), D15.1 (K), D16.1 (K), D17.1 (K), D18.1 (K), D19.1 (K), D20.1 (K), D21.1 (K), D22.1 (K), D23.1 (K), D24.1 (K), U3.40 (GPIO28/ADC2)
ROW2: D25.1 (K), D26.1 (K), D27.1 (K), D28.1 (K), D29.1 (K), D30.1 (K), D31.1 (K), D32.1 (K), D33.1 (K), D34.1 (K), D35.1 (K), D36.1 (K), U3.29 (GPIO18)
ROW3: D37.1 (K), D38.1 (K), D39.1 (K), D40.1 (K), D41.1 (K), D42.1 (K), D43.1 (K), D44.1 (K), D45.1 (K), D46.1 (K), D47.1 (K), D48.1 (K), D49.1 (K), U3.31 (GPIO20)
VBUS: F1.1, J1.A4 (VBUS), J1.A9 (VBUS), J1.B4 (VBUS), J1.B9 (VBUS)
XIN: C15.2, U3.20 (XIN), Y1.3
XOUT: R9.2, U3.21 (XOUT)

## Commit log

2026-02-06 Add Koiboard2 KiCad project and gerbers
    Add the full Koiboard2 KiCad project and generated fabrication artifacts. Files added include .kicad_pro, .kicad_sch, .kicad_pcb, fabrication-toolkit options, keyautoplace log, production backups/zip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
    [keyboard-B_Cu.gbr, keyboard-B_Mask.gbr, keyboard-B_Paste.gbr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]
2026-02-07 silkscreen update
    [koiboard2.kicad_pcb]
2026-02-09 update
    new 3d files, stab removed, logo moved, 2x1u <-> 2u support, cleanup, pcb dxf, ect...
    [blue.step, koiboard2-Edge_Cuts.dxf, koiboard2-User_Eco2.dxf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]
2026-02-15 added 3 switches for the space bar
    [koiboard2-Edge_Cuts.dxf, koiboard2-User_Eco2.dxf, koiboard2.kicad_pcb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]
2026-02-15 added usbc connector 3d model
    [koiboard2.kicad_pcb, koiboard222.step]
2026-02-15 created 2D plate design and exported that into an svg
    [koiboard2.kicad_pcb]
2026-02-26 update from review
    [buttons.kicad_sch, crystal.kicad_sch, flash_memory.kicad_sch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]
2026-03-07 4 layers
    [crystal.kicad_sch, koiboard2.kicad_pcb, koiboard2.kicad_sch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]
2026-03-12 routed matrix
    [koiboard2.kicad_pcb, processor.kicad_sch]
2026-03-13 drc errors fix
    [koiboard2.kicad_pcb, matrix.kicad_sch]
2026-03-24 idk bom stuff
    [koiboard2.kicad_pcb]
2026-03-30 final(?) update
    [Body1.stl, buttons.kicad_sch, case.3mf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]
2026-04-10 2 layer final
    [case.3mf, case.stl, koiboard2_4layer.kicad_pcb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]
2026-04-10 Update pcb 3d render.png
